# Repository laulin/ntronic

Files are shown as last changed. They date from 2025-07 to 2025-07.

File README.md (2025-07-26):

# ntronic

## 🔧 About This Project

Welcome to this open-source educational electronics game designed to help children (and curious adults!) **discover the basics of electricity and electronics through hands-on experimentation**.

The game is made of **modular blocks** that can be easily assembled to create functioning electric circuits — from simple switches to more complex logic and sensor-based modules.

## 🧲 Magnetic Connections

Each module connects to others using **two magnets** and a **metal contact tab**, making assembly intuitive, secure, and fun. There's no need for wires or tools — just snap and play!

## ⚡ Safe and Kid-Friendly

The system runs on **5V**, ensuring **no electrical hazard**. It’s completely safe for supervised educational use and perfect for STEM discovery at home or in the classroom.

## 🧩 Modular System

All blocks follow a **60x60mm base size**, but larger modules can be built using multiples of that base unit. For example, the `power_supply` module is a **1x2 block (60x120mm)** to accommodate additional electronics.

## 🔌 USB-C Power with Built-in Safety

Power is supplied through a dedicated `power_supply` module using **USB-C**. This module also acts as a **circuit breaker**, protecting the system from short circuits and misuse — so you can explore without worry.

# Disclaimer
This project is provided **free of charge** and as **open-source software**, with the primary goal of helping children learn the fundamentals of electricity and electronics.

You are welcome to build, use, and modify this project. However, the following conditions apply:

- **Attribution Requirement**: If you remix, modify, or redistribute this project in any form, you must provide a clear and visible link to this original repository.

- **Commercial Use Prohibited**: Unless you have received explicit written permission from the author, you are strictly prohibited from using any part of this project for commercial purposes. This includes, but is not limited to, selling the code, 3D models, PCBs, kits, or derived products.

- **Safety Notice**: This educational game is not suitable for children under 36 months due to small parts that may pose a choking hazard. Adult supervision by a competent person is required at all times during assembly and use.

This repository contains software code, 3D-printable models, and PCB design files required to build the physical modules.

By using this repository, you acknowledge and agree to comply with these conditions. See LICENCE.txt for more details.

# Quick start guide

## 🛠️ Required Tools and Materials

Before you get started building your own educational electronics kit, make sure you have the following **tools** and **materials** on hand:

### 🧰 Tools

* **3D Printer**
  A 3D printer is required to print the module enclosures. I personally use a **Bambu Lab X1C with AMS** to enable easy color changes for markings.

* **Small Phillips screwdriver**
  Used to install the **metal contact tabs** (battery terminal-style connectors) inside the modules.

* **Soldering iron**
  Needed to insert **brass heat-set inserts** into the printed parts.

* **Hex key for M3 screws**
  Required for assembling the modules with M3 screws.

### 🧱 Materials

* **PETG Filament**
  PETG is recommended for its **durability and resistance to rough handling by children**.

  * I use **gray** for the base parts and **yellow** for the **"tops"** (the removable lids).
  * If your printer doesn’t support multi-color prints, you can **add markings manually** using **paint** or a **permanent marker**.
  * Recommended brand: **Overture PETG**.

* **Brass M3 heat-set inserts**
  Example: [Ruthex M3x5.7 Inserts (Amazon link)](https://www.amazon.fr/dp/B08BCRZZS3)

* **AAA battery-type metal contact tabs**
  Used as connection terminals between modules.
  Example: [AliExpress product link](https://fr.aliexpress.com/item/32946601230.html)

* **M2x6 screws**
  Example: [Amazon link](https://www.amazon.fr/dp/B0CH9ZXMSK)

* **M3x10 screws**
  Example: [Amazon link](https://www.amazon.fr/dp/B0DN79L3NP)

* **20–22 AWG wire**
  Standard insulated wire for connecting components inside the modules.

> 🔧 Additional tools and materials may be required depending on the specific module you're building. These will be listed in each module’s construction guide.

## 📁 Repository Structure

This repository is organized to make it easy for makers to explore, print, and build each module.

### 🧩 `modules/` Directory

This is the core directory containing **all available modules**. Each module has its own subfolder, structured as follows:

```
modules/
├── led/
├── button/
├── power_supply/
├── ...
└── bases/
```

#### 📦 Module folders (`led/`, `button/`, etc.)

Each folder represents a **self-contained module** and includes:

* One or more **STL files** for 3D printing (at minimum, a `top.stl` for the lid)
* **Preview images** (same name as the STL, e.g., `top.png`) for visual reference
* Optionally:

  * A `PCB/` folder with files for the **custom circuit board**
  * A folder for **firmware** or **code** (if the module is programmable)
  * Additional documentation
* A `README.md` explaining the module's purpose, required components, and how to assemble it

#### 🧱 Special folder: `bases/`

This folder contains **base enclosures** used by other modules.
Each module specifies **which base it builds upon** (e.g., 1x1, 1x2…).

Think of it as the physical "shell" shared by multiple modules.

---

This structure ensures modularity and reuse, making it easy to:

* Print only what you need
* Understand how each part fits together
* Extend the project with your own creations

## 🖨️ 3D Printing Instructions

All modules are designed to be easy to print with standard FDM 3D printers. Here are some recommended print settings to ensure optimal results:

### 🔧 Recommended Settings

* **Nozzle size**: `0.6 mm`
  A slightly larger nozzle helps speed up prints and improves durability.

* **Layer height**: `0.3 mm`
  Perfect balance between print speed and detail.

* **Top/Bottom shell layers**: `4`
  This ensures a clean and solid finish on all surfaces.

* **Top/Bottom surface pattern**: `Hilbert Curve`
  Produces a visually appealing texture while hiding minor imperfections.

* **Build plate**:
  A **textured plate** is recommended to minimize surface defects and improve adhesion.

---

### ⚠️ Support and Adhesion Notes

Unless explicitly mentioned in a module's README:

* **No support structures** are required
* **No raft or brim** is necessary

All parts are designed to be **printable flat on the bed** without extra processing.

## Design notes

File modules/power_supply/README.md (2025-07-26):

# ⚡ Module: Power Supply

**Warning:** **Never include more than one `power_supply` module in a single circuit**—this can damage components!

This module provides safe 5V power to the rest of your circuit via a **USB‑C connector** (e.g. [Amazon product link](https://www.amazon.fr/dp/B0D3X3QPD1)) and includes built‑in short‑circuit protection.

---

## 🎨 3D Models

Please print the following parts:

* `top.stl`
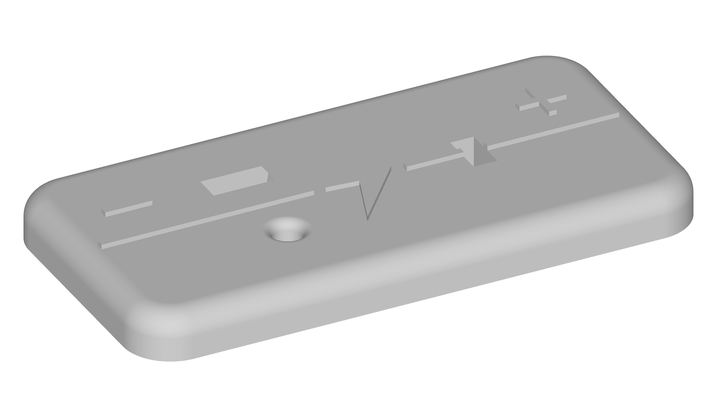
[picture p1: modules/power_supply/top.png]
  
  (If possible, print in two colors for contrast)

* `window.stl`
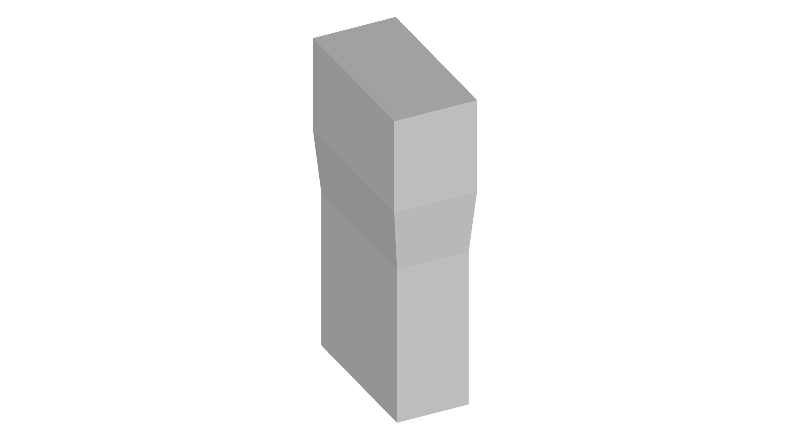
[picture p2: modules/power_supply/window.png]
  
  (Use **transparent filament** so you can see LED indicators)

* `button.stl`
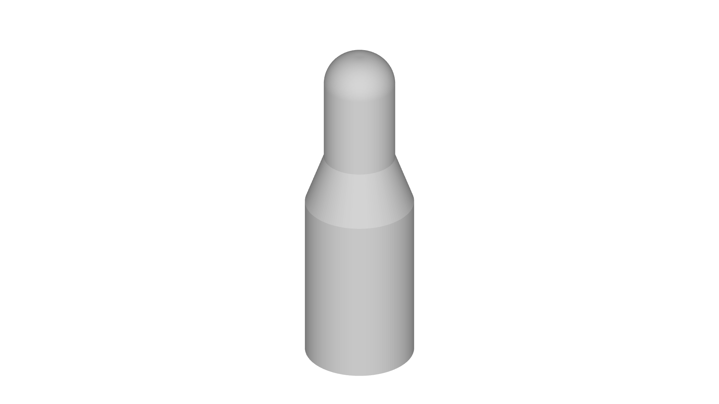
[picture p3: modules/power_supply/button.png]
  
  (Print in a bright color for visibility)

* Base: `bases/base_line_1x2.stl`
  (Standard 1×2 base)
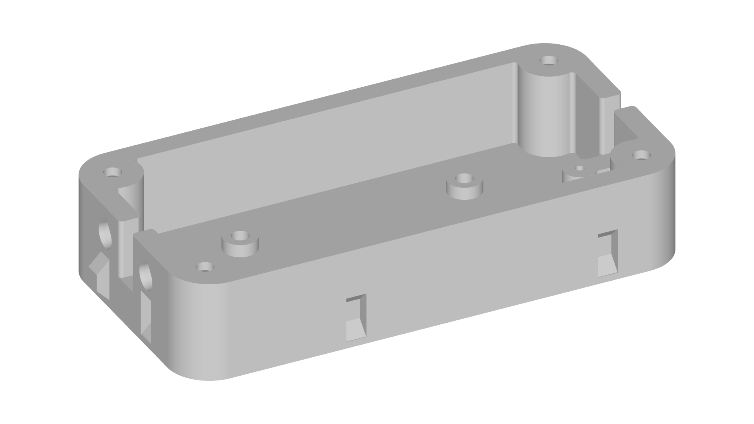
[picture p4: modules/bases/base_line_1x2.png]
  

After printing, insert the **brass inserts** into the `top` piece using a soldering iron before assembly and screws metal contacts in the `base`. 

---

## 🔩 PCB Assembly & Flashing

Inside the `pcb/` directory, you’ll find:

* Gerber files
* Pick‑and‑place file
* BOM (Bill of Materials)

### 🛠️ Manufacturing Your PCB

You can manufacture and assemble the PCB using any PCB fabrication service. You can follow this [tutorial](https://train-science.com/order-pcbs-easily-at-jlcpcb-a-step-by-step-guide/)

### 🧠 Installing Arduino Nano & Flashing Firmware

Mount an **Arduino Nano** on the PCB socket, and solder it in place. Once soldered:

* Open the Arduino IDE.
* Select your board: **Arduino Nano**.
* Choose the correct port under **Tools > Port**.
* Load the `power_supply.ino` sketch and click **Upload**.

---

## 🔌 Wiring & Final Assembly

1. **Wire connections**

   * **P1**: USB‑C input connector
   * **P2**: Metal tabs for connecting other modules
   * Be extra careful: make sure polarity is correct when wiring!

2. **Enclosure & buttons**

   * Insert `window.stl` into the `top` shell so LEDs are visible
   * Snap in the `button.stl` part
   * Attach the `top` to the base with screws into the brass inserts

And… **TADA!** Your power module is complete.

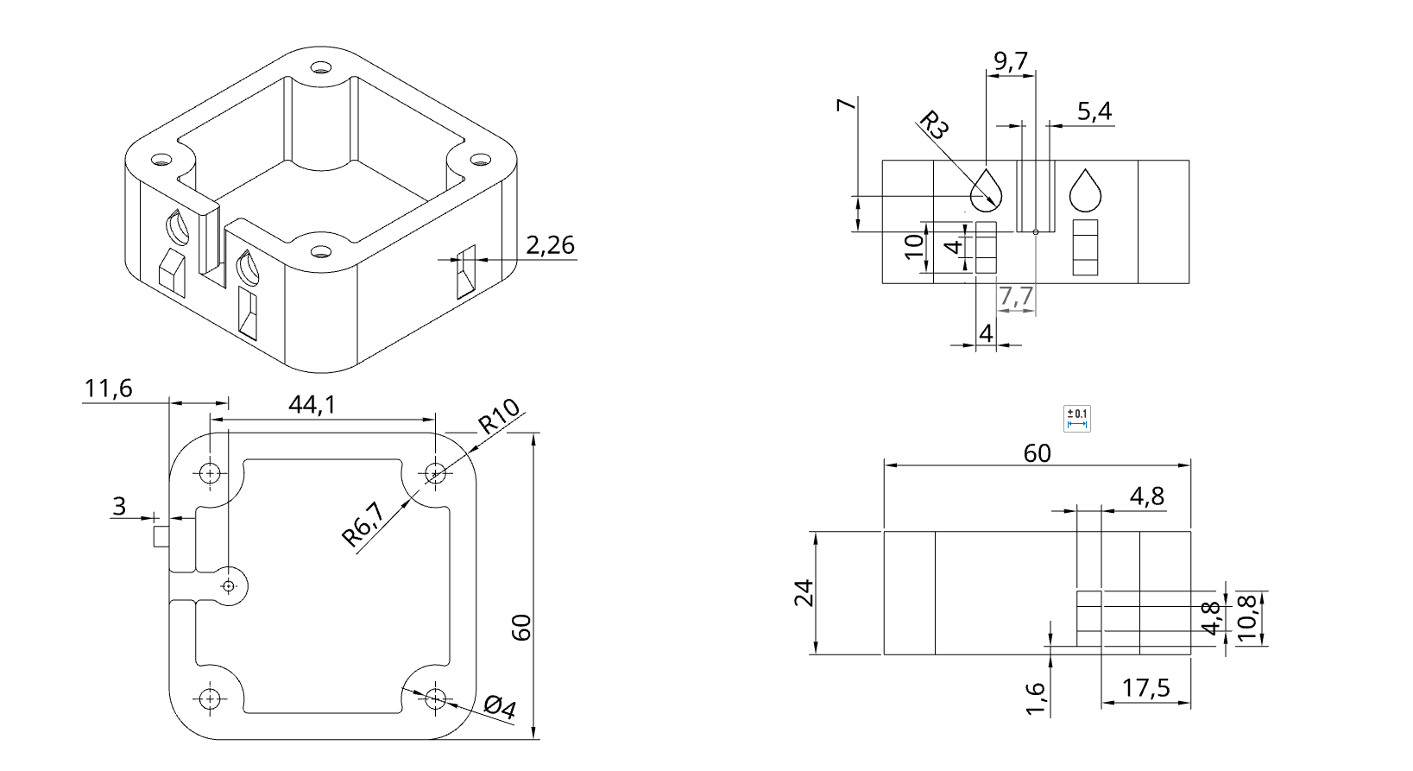
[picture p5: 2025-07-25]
images/blueprint.png

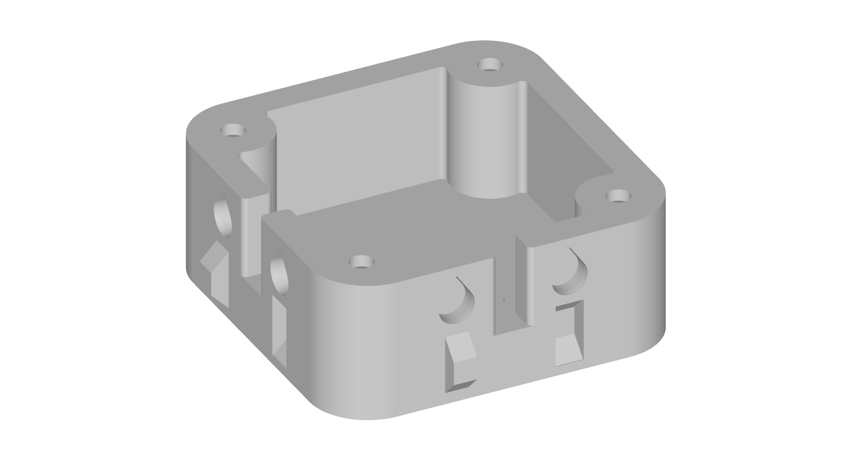
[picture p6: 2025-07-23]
modules/bases/base_C_1x1.png

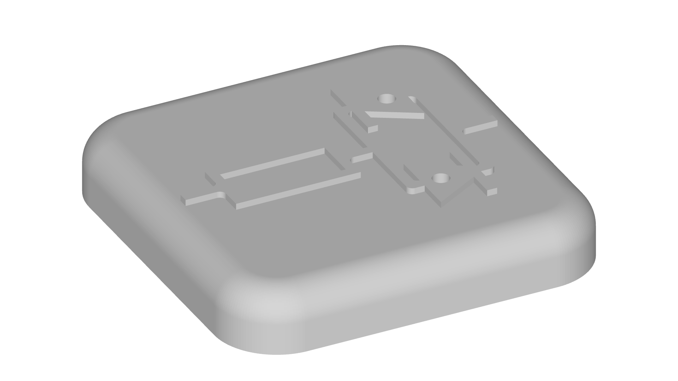
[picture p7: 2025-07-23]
modules/dual-leds/top.png

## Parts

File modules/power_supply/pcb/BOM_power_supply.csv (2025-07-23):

ID | Name | Designator | Footprint | Quantity | Manufacturer Part | Manufacturer | Supplier | Supplier Part | Price | JLCPCB Part Class
1 | ARDUINO-NANO-3.0#ISP | M1 | ARDUINO-NANO-3.0#ISP | 1
2 | 100nF | C1,C2,C3 | C0402 | 3 | CL05B104KO5NNNC | SAMSUNG(三星) | LCSC | C1525 | 0.001 | Basic Part
3 | KT-0603R | LED1 | LED0603-RD | 1 | KT-0603R | KENTO | LCSC | C2286 | 0.006 | Basic Part
4 | 0805G (Green) | LED2 | LED0805-R-RD | 1 | KT-0805G | KENTO | LCSC | C2297 | 0.011 | Basic Part
5 | 0603White light_C2290 | LED3 | LED0603-R-RD_WHITE | 1 | KT-0603W | KENTO | LCSC | C2290 | 0.01 | Basic Part
6 | SI2301CDS-T1-GE3 | Q1 | SOT-23-3_L3.0-W1.7-P0.95-LS2.9-BR | 1 | SI2301CDS-T1-GE3 | VISHAY(威世) | LCSC | C10487 | 0.06 | Basic Part
7 | 3.3kΩ | R2,R3 | R0402 | 2 | 0402WGF3301TCE | UNI-ROYAL(厚声) | LCSC | C25890 | 0.001 | Basic Part
8 | 1kΩ | R4 | R0402 | 1 | 0402WGF1001TCE | UNI-ROYAL(厚声) | LCSC | C11702 | 0.001 | Basic Part
9 | 100kΩ | R5 | R0402 | 1 | 0402WGF1003TCE | UNI-ROYAL(厚声) | LCSC | C25741 | 0.001 | Basic Part
10 | 10Ω | R6,R7 | R0402 | 2 | 0402WGF100JTCE | UNI-ROYAL(厚声) | LCSC | C25077 | 0.001 | Basic Part
11 | 330Ω | R8,R9,R10 | R0402 | 3 | 0402WGF3300TCE | UNI-ROYAL(厚声) | LCSC | C25104 | 0.001 | Basic Part
12 | TS-1088-AR02016 | SW1 | SW-SMD_L3.9-W3.0-P4.45 | 1 | TS-1088-AR02016 | XUNPU(讯普) | LCSC | C720477 | 0.042 | Basic Part
13 | WJ500V-5.08-2P-14-00A | P1,P2 | CONN-TH_2P-P5.00_WJ500V-5.08-2P | 2 | WJ500V-5.08-2P | KANGNEX(康奈克斯电气) | LCSC | C8465 | 0.095 | Extended Part
14 | 100mΩ | R1 | R2512 | 1 | HoLLR2512-3W-100mR-1% | Milliohm(毫欧) | LCSC | C2994646 | 0.083 | Extended Part
15 | INA219AID | U1 | SOIC-8_L4.9-W3.9-P1.27-LS6.0-BL | 1 | INA219AID | TI(德州仪器) | LCSC | C1574856 | 2.9 | Extended Part

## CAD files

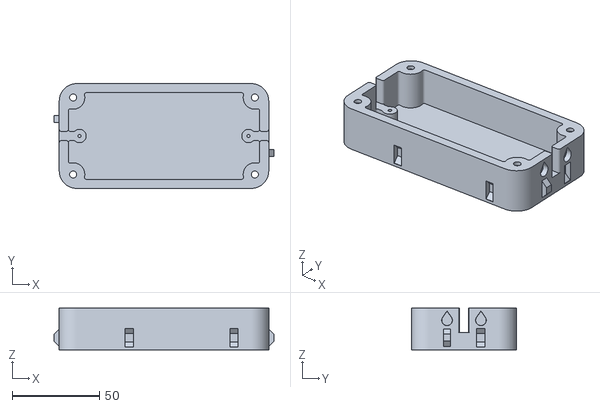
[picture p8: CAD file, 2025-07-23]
modules/bases/base_line_1x2.stl
126.0 x 60.0 x 24.0

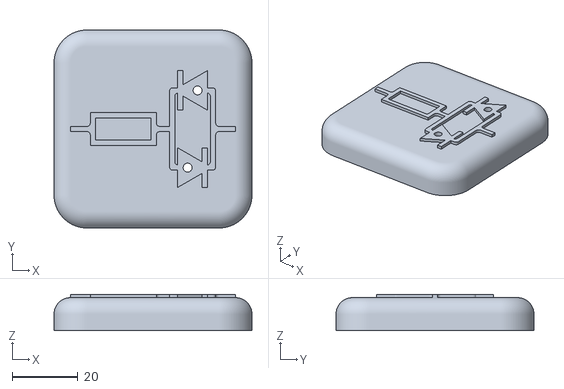
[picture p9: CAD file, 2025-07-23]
modules/dual-leds/top.stl
60.0 x 60.0 x 11.0

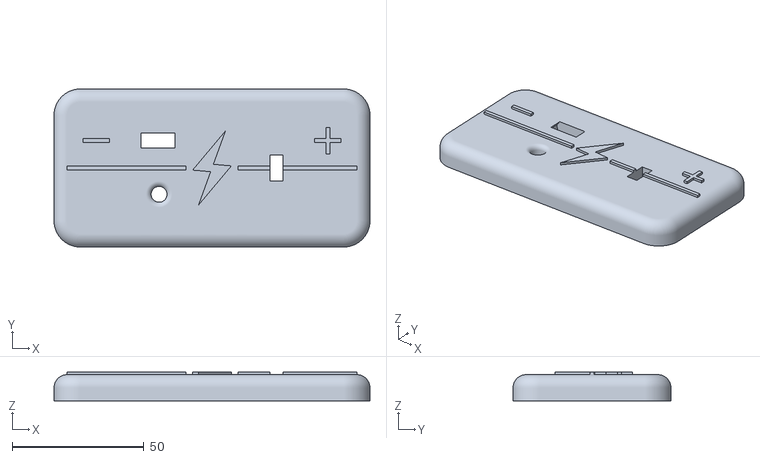
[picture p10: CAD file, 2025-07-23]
modules/power_supply/top.stl
120.0 x 60.0 x 11.0

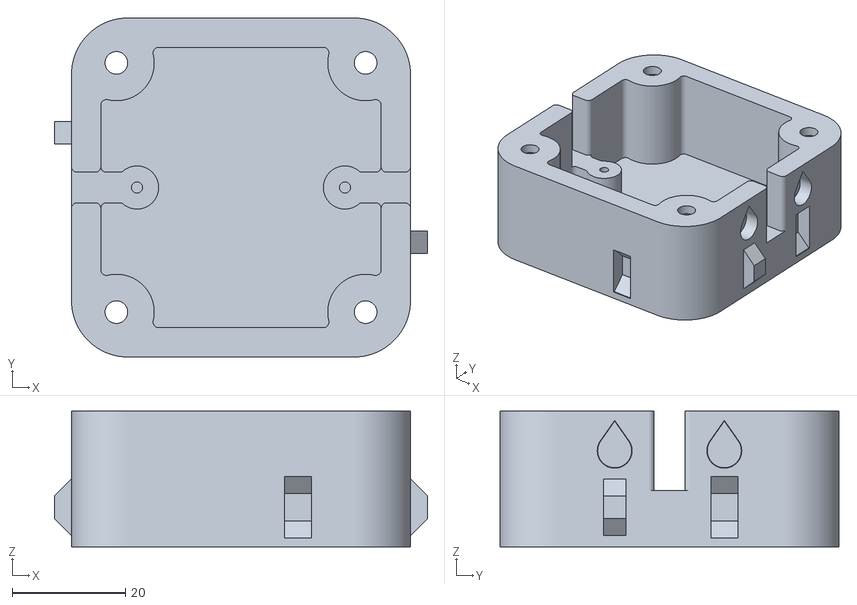
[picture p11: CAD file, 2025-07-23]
modules/bases/base_line_1x1.stl
66.0 x 60.0 x 24.0

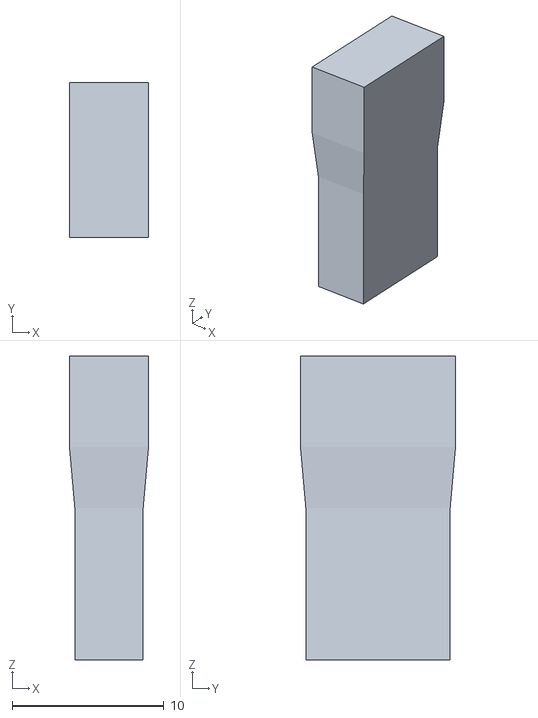
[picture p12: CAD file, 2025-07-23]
modules/power_supply/windows.stl
5.20 x 10.2 x 20.0

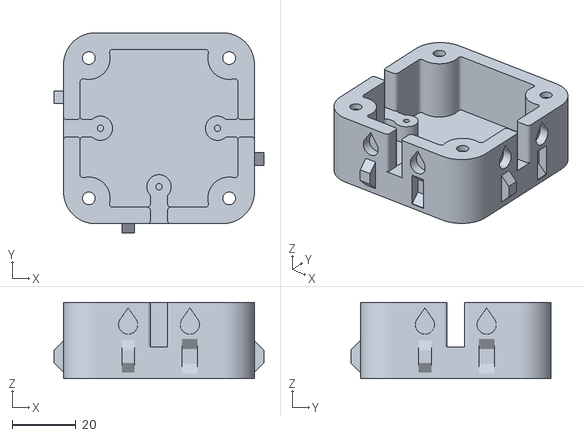
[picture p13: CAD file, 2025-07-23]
modules/bases/base_T_1x1.stl
66.0 x 63.0 x 24.0

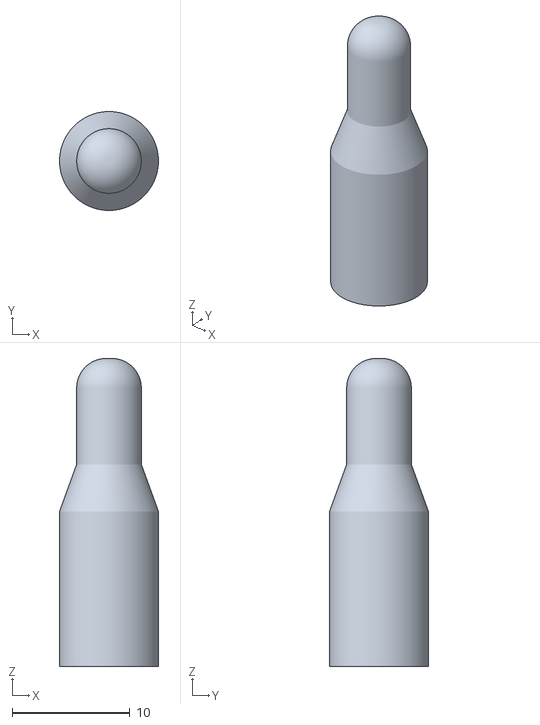
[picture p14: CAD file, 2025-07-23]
modules/power_supply/button.stl
8.41 x 8.41 x 26.2

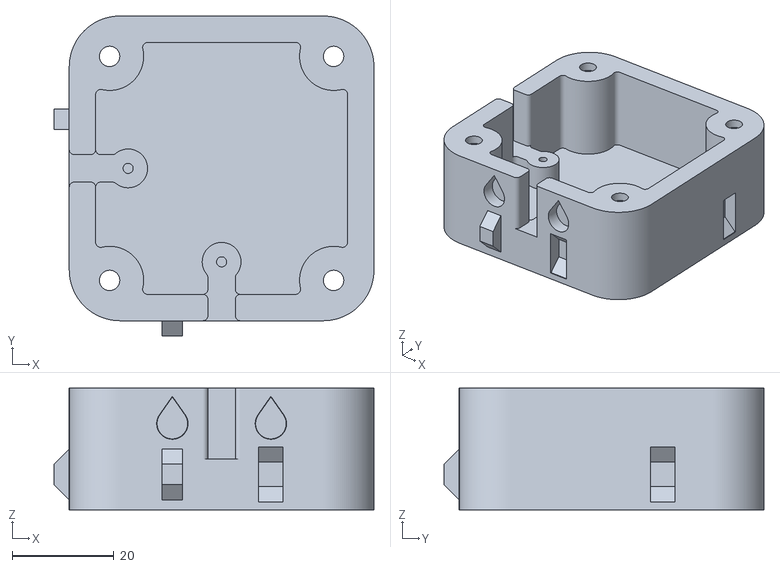
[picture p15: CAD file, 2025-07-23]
modules/bases/base_C_1x1.stl
63.0 x 63.0 x 24.0

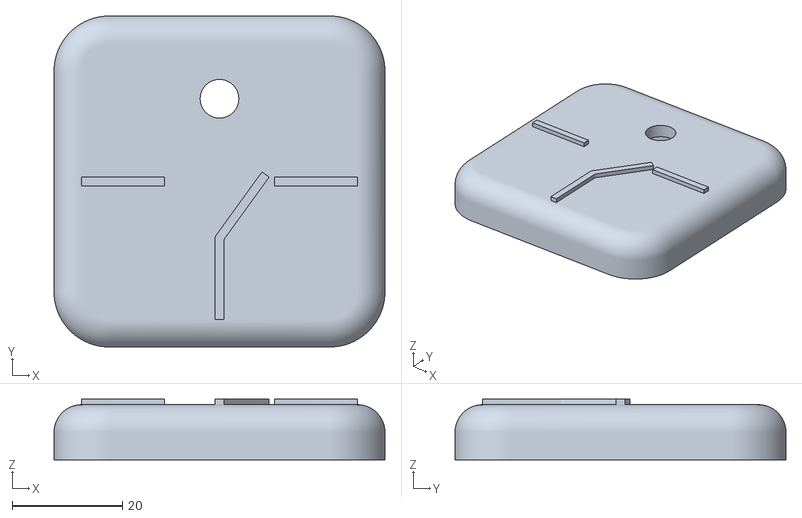
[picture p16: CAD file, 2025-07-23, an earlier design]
modules/toggle/top.stl
60.0 x 60.0 x 11.0

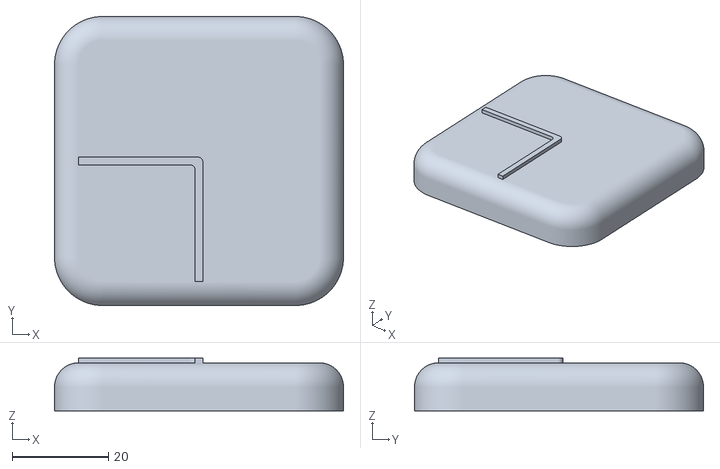
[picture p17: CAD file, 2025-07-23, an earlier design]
modules/wire-corner/top.stl
60.0 x 60.0 x 11.0

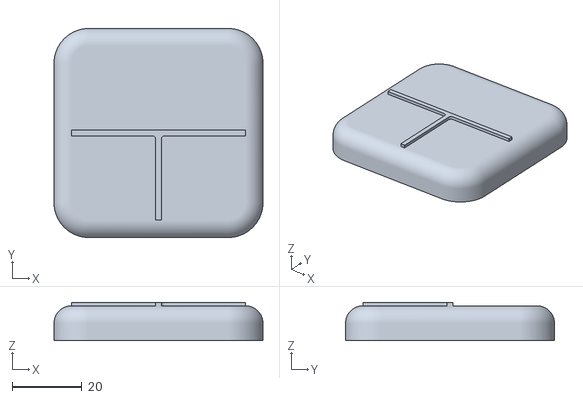
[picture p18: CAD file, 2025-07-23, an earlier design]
modules/wire-T/top.stl
60.0 x 60.0 x 11.0

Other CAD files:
modules/switch/top.stl
modules/wire-line/top.stl

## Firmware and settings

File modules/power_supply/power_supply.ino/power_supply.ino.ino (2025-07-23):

#include <Wire.h>
#include <Adafruit_INA219.h>

// defining pinout
#define RED_PIN 2
#define GREEN_PIN 3
#define WHITE_PIN 4
#define OUTPUT_CTRL_PIN 5
#define BUTTON_PIN 13
#define SHUNT_CONDUCTANCE 10 // 0.100 Ohm

// defining constants
#define DEBOUNCER_THRESHOLD 100 // used to wait a stable state of the button
#define MAX_CURRENT 500 // define the mix current in mA
#define MIN_WHITE_LIGHT 50 // time of the white led

// defining states
#define STATE_INIT  0
#define STATE_RUN  1
#define STATE_ERROR  2

#define LED_ON 0
#define LED_OFF 1

#define OUTPUT_ON 0
#define OUTPUT_OFF 1

Adafruit_INA219 ina219; // current sensor

// counter
long last_time;
int counter;
int debouncer_counter;
// state of the state machine
int state = STATE_INIT;

void setup() {
  // init pinout
  pinMode(RED_PIN, OUTPUT);
  pinMode(GREEN_PIN, OUTPUT);
  pinMode(WHITE_PIN, OUTPUT);
  pinMode(OUTPUT_CTRL_PIN, OUTPUT);

  pinMode(BUTTON_PIN, INPUT_PULLUP);

  digitalWrite(RED_PIN, LED_ON);
  digitalWrite(GREEN_PIN, LED_ON);
  digitalWrite(WHITE_PIN, LED_ON);
  digitalWrite(OUTPUT_CTRL_PIN, OUTPUT_OFF);

  // init current sensor
  if (! ina219.begin()) {
    while (1) { delay(10); }
  }
  ina219.setCalibration_16V_400mA();

  digitalWrite(RED_PIN, LED_OFF);
  digitalWrite(GREEN_PIN, LED_OFF);
  digitalWrite(WHITE_PIN, LED_OFF);

  // init counters
  counter = 0;
  last_time = millis();
  state = STATE_INIT;
  debouncer_counter = 0;

}

void read_button_and_change_state(int next_state){
  if(digitalRead(BUTTON_PIN)==0){
    debouncer_counter++;
  }else{
    if (debouncer_counter > DEBOUNCER_THRESHOLD) {
      state = next_state;
    }
    debouncer_counter = 0;
  }
}

void state_init(){
  digitalWrite(RED_PIN, LED_ON);
  digitalWrite(GREEN_PIN, LED_OFF);
  digitalWrite(WHITE_PIN, LED_OFF);
  digitalWrite(OUTPUT_CTRL_PIN, OUTPUT_OFF);
  
  read_button_and_change_state(STATE_RUN);

}

void state_run(){
  float shuntvoltage = 0;
  int current_mA = 0;

  digitalWrite(RED_PIN, LED_OFF);
  //digitalWrite(GREEN_PIN, LED_ON);
  digitalWrite(OUTPUT_CTRL_PIN, OUTPUT_ON);

  shuntvoltage = ina219.getShuntVoltage_mV();
  current_mA = int(shuntvoltage * SHUNT_CONDUCTANCE);

  // prevent short cut
  if (current_mA >= MAX_CURRENT){
    state = STATE_ERROR;
    counter = 0;
    return;
  }

  counter++ ;
  if (counter < MIN_WHITE_LIGHT){
    digitalWrite(WHITE_PIN, LED_ON);
    digitalWrite(GREEN_PIN, LED_OFF);
  }else{
    digitalWrite(WHITE_PIN, LED_OFF);
    digitalWrite(GREEN_PIN, LED_ON);
    if (counter > (max(MAX_CURRENT<<2 - current_mA<<2, 1) + MIN_WHITE_LIGHT)){
      counter = 0;
    }
  }

  read_button_and_change_state(STATE_INIT);
}

void state_error(){
  digitalWrite(GREEN_PIN, LED_OFF);
  digitalWrite(WHITE_PIN, LED_OFF);
  digitalWrite(OUTPUT_CTRL_PIN, OUTPUT_OFF);

  int red_light_state = (counter >> 7) & 1;
  digitalWrite(RED_PIN, red_light_state);


  read_button_and_change_state(STATE_RUN);

  counter++;
  delay(1);

}

void loop() {
  switch(state){
    case STATE_INIT:
      state_init();
      break;
    case STATE_RUN:
      state_run();
      break;
    case STATE_ERROR:
      state_error();
      break;
    default:
      state = STATE_INIT;
  }
}

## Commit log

2025-07-23 add power supply
    [bottom.stl, button.stl, top.stl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]
2025-07-23 add wires
    [base_C_1x1.stl, base_T_1x1.stl, base_line_1x1.stl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]
2025-07-23 add switches
    [top.stl]
2025-07-23 add leds
    [top.stl]
2025-07-23 add bases
    [base_C_1x1.stl, base_T_1x1.stl, base_line_1x1.stl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]
2025-07-23 add power supply PCB files
    [BOM_power_supply.csv, PickAndPlace_PCB_power_supply.csv]
2025-07-23 change max current and led behavious
2025-07-23 add stl previous in power supply
2025-07-23 remove bases models from modules
    [base_C_1x1.stl, base_T_1x1.stl, base_line_1x1.stl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]
2025-07-25 move modules to modules directory
    [BOM_power_supply.csv, PickAndPlace_PCB_power_supply.csv, base_C_1x1.stl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]
2025-07-25 add required tools and material
2025-07-25 split modules
    [top.stl]
2025-07-26 rename leds to dual leds
    [top.stl]
2025-07-26 add powersupply readme
2025-07-26 update power supply readme
2025-07-26 add printing instructions
